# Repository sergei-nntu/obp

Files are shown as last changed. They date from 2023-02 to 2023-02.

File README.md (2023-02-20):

# Open Battery Pack (OBP-1)

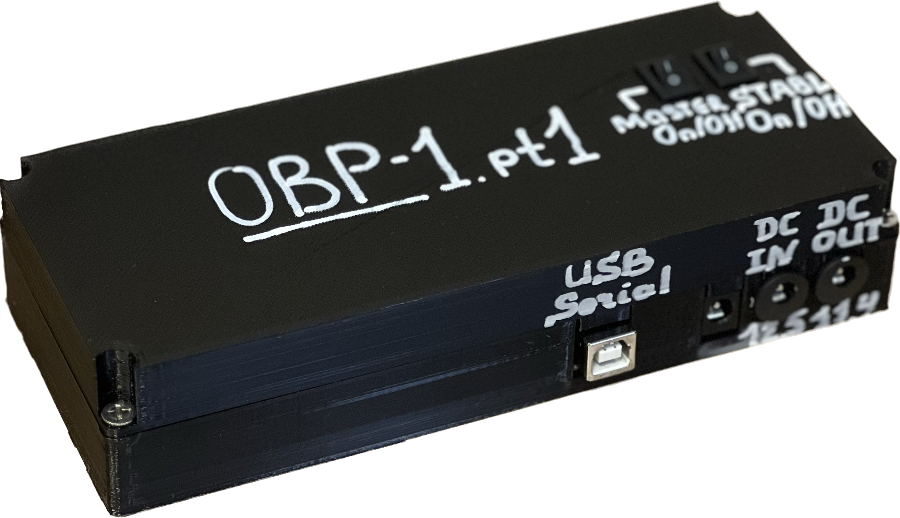
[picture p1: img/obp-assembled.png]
OBP Assembled


Arduino-based open-source hardware power bank for DIY and Robotic applications. This repository contains the schematics, Arduino firmware, python library for connection from the computer and FreeCAD case design files. 

# Installing Arduino code
Arduino source code is located in folder `src/arduino/OpenBatteryPack`. Open it with Arduino IDE and flash it into your Arduino board.

# Python library example
Flash the Arduino firmware into your board. Make sure it is connected through USB. Then run the example:

`cd src/python`

`python3 example.py`

# Technical Documentation
The architecture documentation can be found in `doc` folder.

# Case 3D Printing
STL files for 3d printing can be found in `case` folder. 
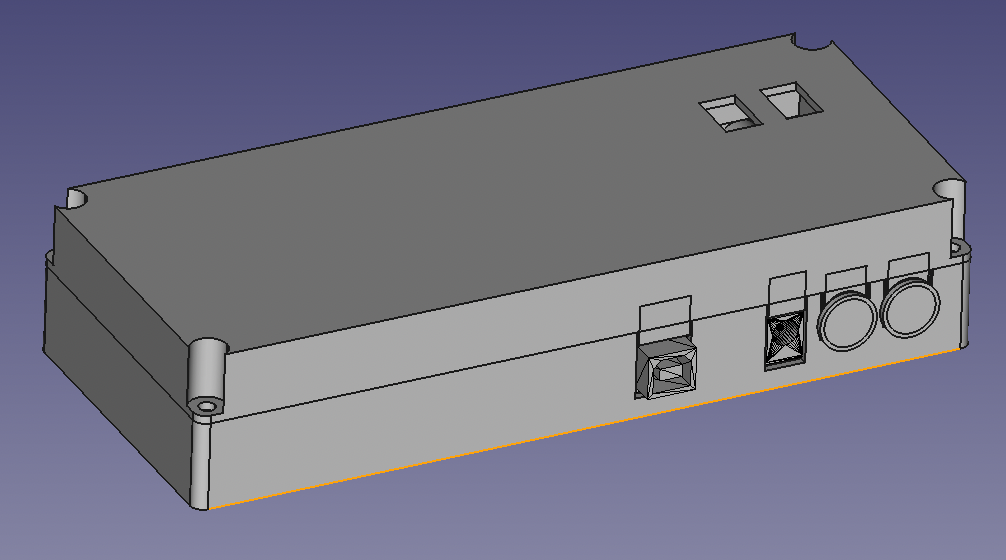
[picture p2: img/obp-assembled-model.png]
OBP Assembled Model


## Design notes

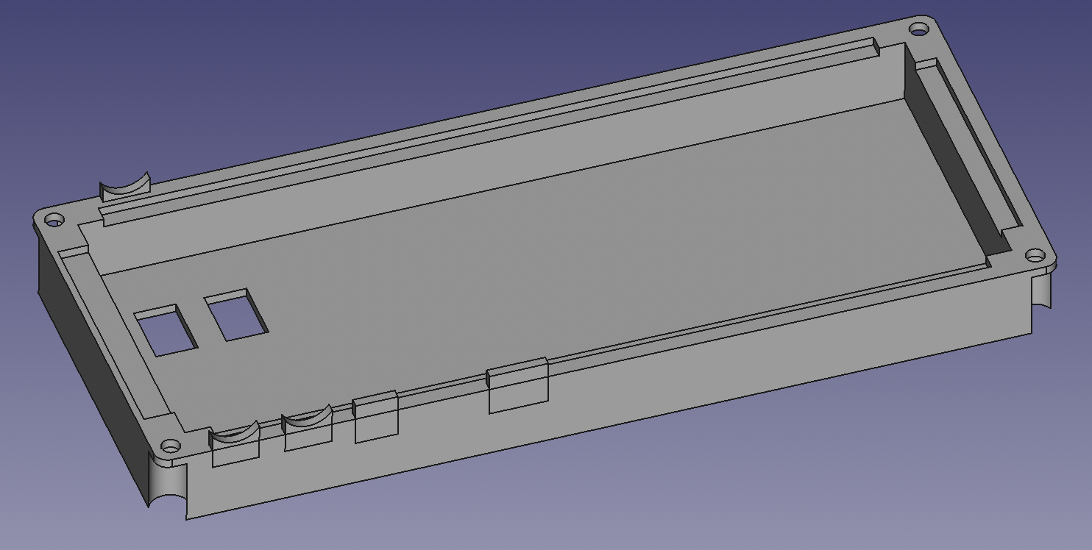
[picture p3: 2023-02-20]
img/obp-cover-model.png

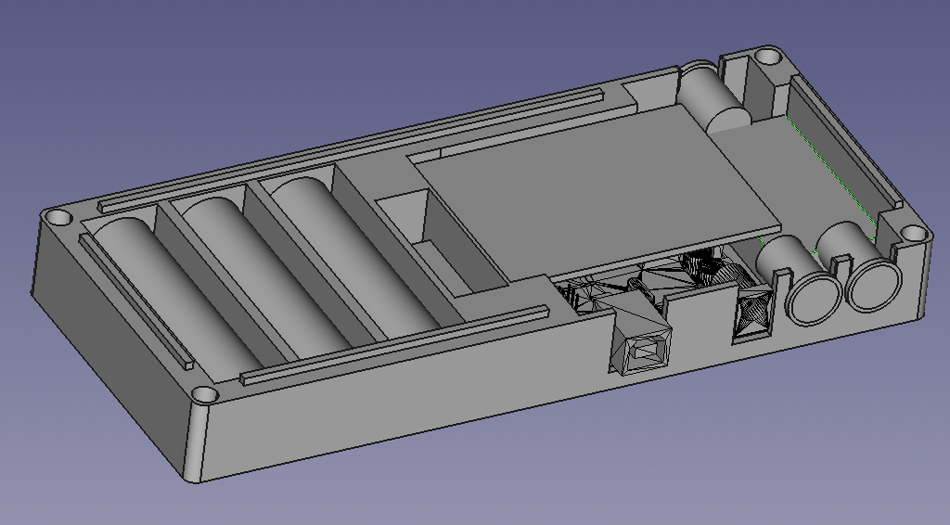
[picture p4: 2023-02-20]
img/obp-case-model.png

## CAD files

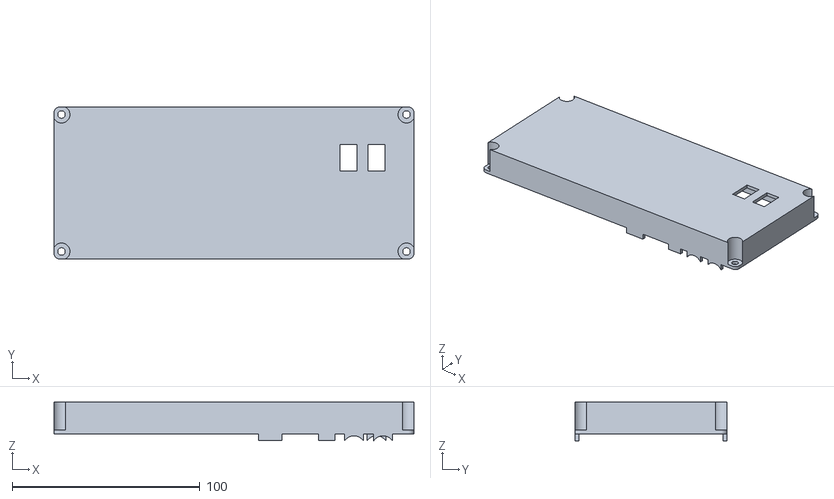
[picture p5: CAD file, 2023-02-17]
case/OBP_1_cover.stl
192.0 x 81.0 x 20.7

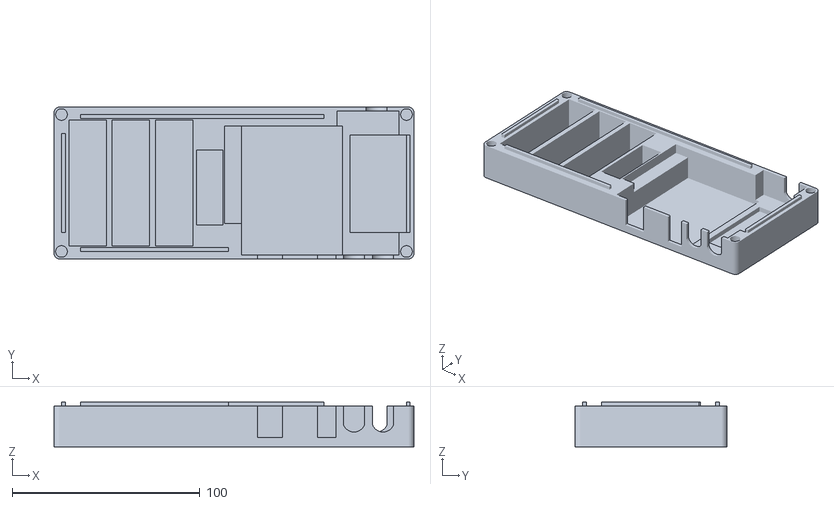
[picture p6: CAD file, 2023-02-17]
case/OBP_1_case.stl
192.0 x 81.0 x 24.0

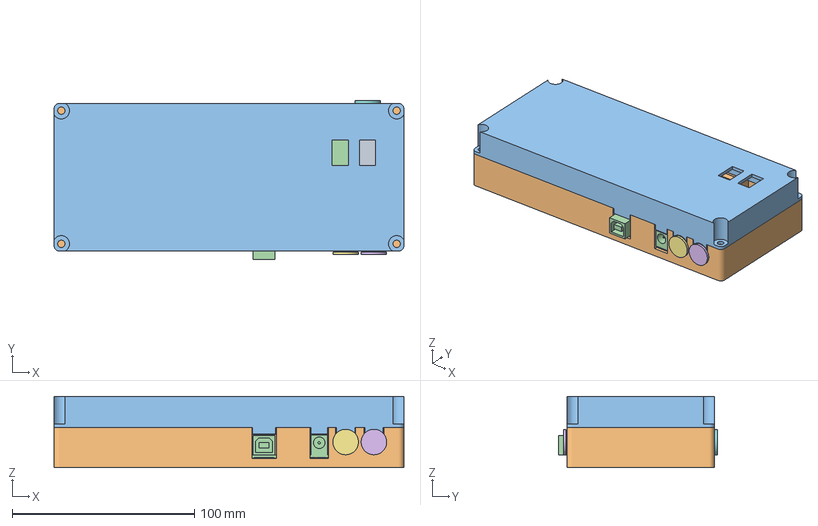
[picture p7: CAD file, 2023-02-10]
case/OpenBatteryPack_pt1.FCStd
192.0 x 87.0 x 39.0 mm
18650 Battery
18650 Battery001
18650 Battery002
Main Board
Current Sensor
DC Jack
DC Jack001
DC Jack002
DC-DC Step Up
Cover
Arduino.ipt

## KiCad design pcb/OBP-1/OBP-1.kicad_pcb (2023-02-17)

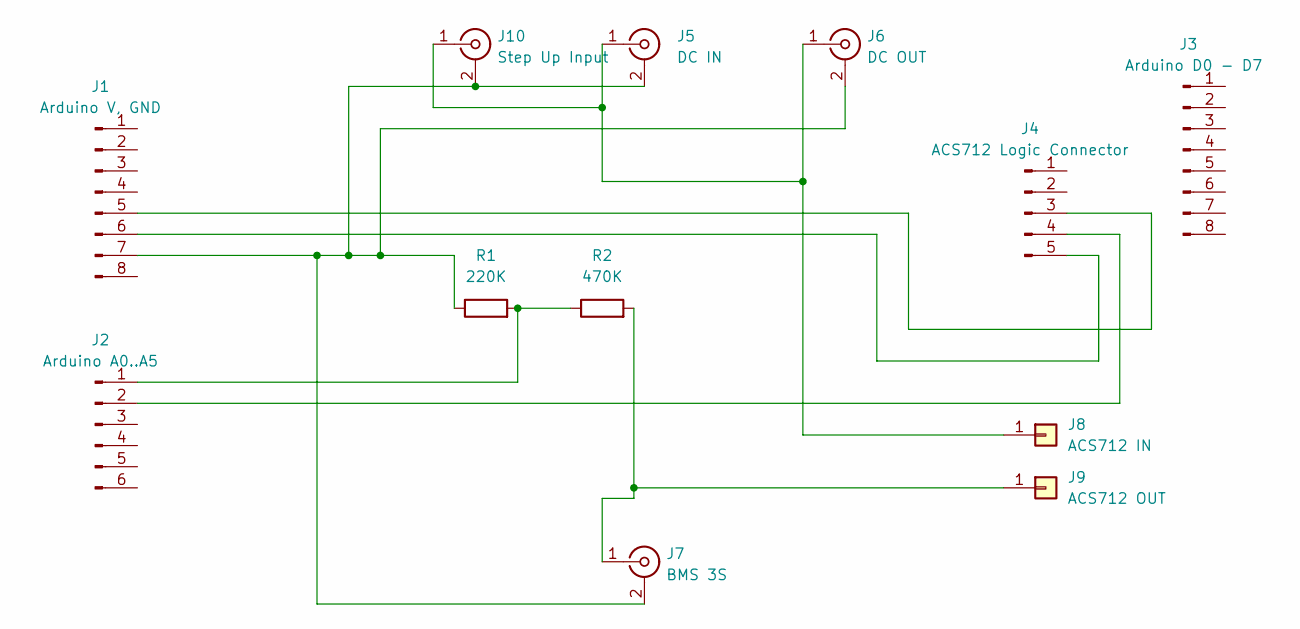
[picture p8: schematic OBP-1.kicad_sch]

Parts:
J1: Arduino V, GND; PinHeader_1x08_P2.54mm_Vertical
J2: Arduino A0..A5; PinHeader_1x06_P2.54mm_Vertical
J3: Arduino D0 - D7; PinHeader_1x08_P2.54mm_Vertical
J4: ACS712 Logic Connector; PinHeader_1x05_P2.54mm_Vertical
J5: DC IN; SolderWire-0.1sqmm_1x02_P3.6mm_D0.4mm_OD1mm
J6: DC OUT; SolderWire-0.1sqmm_1x02_P3.6mm_D0.4mm_OD1mm
J7: BMS 3S; SolderWire-0.1sqmm_1x02_P3.6mm_D0.4mm_OD1mm
J8: ACS712 IN; SolderWire-0.1sqmm_1x01_D0.4mm_OD1mm
J9: ACS712 OUT; SolderWire-0.1sqmm_1x01_D0.4mm_OD1mm
J10: Step Up Input; SolderWire-0.1sqmm_1x02_P3.6mm_D0.4mm_OD1mm
R1: 220K; R_Axial_DIN0207_L6.3mm_D2.5mm_P10.16mm_Horizontal
R2: 470K; R_Axial_DIN0207_L6.3mm_D2.5mm_P10.16mm_Horizontal

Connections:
unnamed: J1.5, J4.3
unnamed: J1.6, J4.5
unnamed: J1.7, J5.2 (Ext), J6.2 (Ext), J7.2 (Ext), J10.2 (Ext), R1.1
unnamed: J2.1, R1.2, R2.1
unnamed: J2.2, J4.4
unnamed: J5.1 (In), J6.1 (In), J8.1, J10.1 (In)
unnamed: J7.1 (In), J9.1, R2.2

Board: 2 copper layers, 12 parts (0 on the bottom side), 7 nets, no tracks yet.

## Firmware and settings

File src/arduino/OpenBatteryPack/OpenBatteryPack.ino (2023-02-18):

#include <EEPROM.h>

#include <LowPower.h>

// BATTERY CHARGE CONTROLLER FUNCTIONS

#define OBP_MAX_CAPACITY 10000 // mAh

int obp_voltage = 0;      // in mV
int obp_current_draw = 0; // in mA
int obp_soc = 2000;       // in mAh

// BATTERY PACK HARDWARE PARAMETERS

#define OBP_MAX_V       12600 // mV
#define OBP_MIN_V       9000  // mV

#define OBP_DIVISOR_R1  220
#define OBP_DIVISOR_R2  470

#define OBP_REF_V       5000
#define OBP_ADC_MAX     1024

#define OBP_V_PIN       A0
#define OBP_I_PIN       A1

#define OBP_STATUS_UNKNOWN        0x00
#define OBP_STATUS_IDLE           0x01
#define OBP_STATUS_DISCHARGING    0x02
#define OBP_STATUS_CHARGING       0x03
#define OBP_STATUS_FULLY_CHARGED  0x04

#define OBP_FSM_STATE_WAITING_FOR_ZERO  0x01
#define OBP_FSM_STATE_ZERO_CURRENT      0x02
#define OBP_FSM_STATE_NON_ZERO_CURRENT  0x03

#define OBP_AFTER_ZERO_ITERATIONS       10  // Number of 8 second intervals to check the voltage drop at non-zero current 

#define OBP_MAX_SENSED_CURRENT  20000   // mA
#define OBP_MIN_SENSED_CURRENT  -20000  // mA
#define OBP_NEAR_ZERO_CURRENT   250 // mA
#define OBP_SIGNIFICANT_CURRENT 1000 // mA
#define OBP_MAX_CURRENT_VOLTAGE 4500 // mV
#define OBP_MIN_CURRENT_VOLTAGE 500 // mV

#define OBP_EEPROM_POS_CURRENT_I_ADDR         0*sizeof(int)
#define OBP_EEPROM_POS_CURRENT_DELTA_U_ADDR   1*sizeof(int)
#define OBP_EEPROM_NEG_CURRENT_I_ADDR         2*sizeof(int)
#define OBP_EEPROM_NEG_CURRENT_DELTA_U_ADDR   3*sizeof(int)

// Corresponds to WAITING_FOR_ZERO state of FSM
unsigned char after_zero_iterations = OBP_AFTER_ZERO_ITERATIONS+1;
unsigned char obp_fsm_state = OBP_FSM_STATE_WAITING_FOR_ZERO;
int last_zero_current_voltage = 0;

unsigned char obp_status = OBP_STATUS_IDLE;

bool obp_flag_low_voltage = false;
bool obp_flag_high_voltage = false;
bool obp_flag_overheat = false;
bool obp_flag_short_circuit= false;

// OPEN SERIAL PERIPHERAL FUNCTIONS

#define OSP_MSG_DEV_INDEX     2
#define OSP_MSG_CMD_INDEX     3
#define OSP_BYTE_PARAM_INDEX      4
#define OSP_INT_PARAM_MSB_INDEX   5
#define OSP_INT_PARAM_LSB_INDEX   4 

#define OSP_DEV_GENERIC       0 
#define OSP_DEV_ORM           1 // Open Robotic Manipulator
#define OSP_DEV_OBP           2 // Open Battery Pack 
#define OSP_DEV_O2D           3 // Open Differential Drive

#define OSP_CMD_REQ_DEV_TYPE  1

#define OSP_OBP_CMD_REQ_SOC       0x01
#define OSP_OBP_CMD_REQ_VOLTAGE   0x02
#define OSP_OBP_CMD_REQ_CURRENT   0x03
#define OSP_OBP_CMD_REQ_STATUS    0x04

#define OSP_INFO_DEV_TYPE         0x11
#define OSP_OBP_INFO_SOC          0x11
#define OSP_OBP_INFO_VOLTAGE      0x12
#define OSP_OBP_INFO_CURRENT      0x13
#define OSP_OBP_INFO_STATUS       0x14

#define OSP_DEV_CURRENT           OSP_DEV_OBP

#define OSP_COMMAND_LENGTH        10
#define OSP_BUFFER_SIZE           10

char            osp_output_buffer[OSP_BUFFER_SIZE];
unsigned char   osp_input_buffer[OSP_BUFFER_SIZE];
int             osp_ptr=0;

const char osp_command_template[] = {0xFF, 0xAA, 0x00, 0x00, 0x00, 0x00, 0x00, 0x00, 0x55, 0x77};

// HANDING OSP GENERIC COMMANDS

void osb_info_dev_type(){
  osp_prepare_output_buffer();
  osp_output_buffer[OSP_MSG_DEV_INDEX] = OSP_DEV_GENERIC;
  osp_output_buffer[OSP_MSG_CMD_INDEX] = OSP_INFO_DEV_TYPE;
  osp_output_buffer[OSP_BYTE_PARAM_INDEX] = OSP_DEV_CURRENT; // Returning the current device type as a parameter
  Serial.write(osp_output_buffer, OSP_COMMAND_LENGTH);
}

void osp_handle_generic_command(){
  int cmd = osp_input_buffer[OSP_MSG_CMD_INDEX];  
  if (cmd == OSP_CMD_REQ_DEV_TYPE) {
    // HERE WE MUST RESPONSE WITH A DEV TYPE
    osb_info_dev_type();
  }
}

void osp_prepare_output_buffer(){
  for(int i=0;i<OSP_BUFFER_SIZE;i++) {
    osp_output_buffer[i] = osp_command_template[i];
  }
}

// HANDLING OBP COMMANDS
void osp_opb_send_info_soc(){
  osp_prepare_output_buffer();
    
  unsigned int soc_int = obp_soc;
  osp_output_buffer[OSP_MSG_DEV_INDEX] = OSP_DEV_OBP;
  osp_output_buffer[OSP_MSG_CMD_INDEX] = OSP_OBP_INFO_SOC;
  osp_output_buffer[OSP_INT_PARAM_LSB_INDEX] = soc_int & 0xFF;
  osp_output_buffer[OSP_INT_PARAM_MSB_INDEX] = soc_int >> 8;
  
  Serial.write(osp_output_buffer, OSP_COMMAND_LENGTH);
}

void osp_opb_send_info_voltage(){
  osp_prepare_output_buffer();
  unsigned int voltage_int = obp_voltage ; // Voltage in mV

  osp_output_buffer[OSP_MSG_DEV_INDEX] = OSP_DEV_OBP;
  osp_output_buffer[OSP_MSG_CMD_INDEX] = OSP_OBP_INFO_VOLTAGE;
  osp_output_buffer[OSP_INT_PARAM_LSB_INDEX] = voltage_int & 0xFF;
  osp_output_buffer[OSP_INT_PARAM_MSB_INDEX] = voltage_int >> 8;
  
  Serial.write(osp_output_buffer, OSP_COMMAND_LENGTH);  
}

void osp_opb_send_info_current(){
  osp_prepare_output_buffer();
  int  current_int = obp_current_draw; // mA 
  osp_output_buffer[OSP_MSG_DEV_INDEX] = OSP_DEV_OBP;
  osp_output_buffer[OSP_MSG_CMD_INDEX] = OSP_OBP_INFO_CURRENT;

  osp_output_buffer[OSP_INT_PARAM_LSB_INDEX] = current_int & 0xFF;
  osp_output_buffer[OSP_INT_PARAM_MSB_INDEX] = current_int >> 8;
   
  Serial.write(osp_output_buffer, OSP_COMMAND_LENGTH);   
}

void osp_opb_send_info_status(){
  
}

void osp_handle_obp_command(){
  int cmd = osp_input_buffer[OSP_MSG_CMD_INDEX];  
  if (cmd == OSP_OBP_CMD_REQ_SOC) {
    // RESPONSE WITH A CURRENT SOC STATE
    osp_opb_send_info_soc();
  }
  if (cmd == OSP_OBP_CMD_REQ_VOLTAGE) {
    // RESPONSE WITH A CURRENT VOLTAGE LEVEL
    osp_opb_send_info_voltage();
  }
  if (cmd == OSP_OBP_CMD_REQ_CURRENT) {
    // RESPONSE WITH A CURRENT CURRENT DRAW
    osp_opb_send_info_current();
  }
  if (cmd == OSP_OBP_CMD_REQ_STATUS) {
    // RESPONSE WITH A CURRENT BATTERY STATUS
    osp_opb_send_info_status();
  }
}

void osp_handle_command(){
  int dev = osp_input_buffer[OSP_MSG_DEV_INDEX];
  
  if (dev == OSP_DEV_GENERIC) {
    osp_handle_generic_command();
  } else if (dev == OSP_DEV_CURRENT) {
    if (dev == OSP_DEV_OBP) {
      osp_handle_obp_command();
    }
  } else {
    // ERROR CONDITION. THE CLIENT MUST NOT SEND THE COMMAND WHICH ARE NOT FOR EITHER GENERIC OR CURRENT DEV TYPE
    // DOING NOTHING FOR NOW
  }
}

void setup_osp(){
  Serial.begin(115200);
  Serial.setTimeout(0.01);  
}

void loop_osp(){
  if(Serial.available()){
    char b = Serial.read();
    if(osp_command_template[osp_ptr]==b || osp_command_template[osp_ptr]==0){
      osp_input_buffer[osp_ptr] = b;
      osp_ptr++; 
      if(osp_ptr==OSP_COMMAND_LENGTH){
        osp_handle_command();
        osp_ptr = 0;
      }
    } else {
      osp_ptr = 0;
    }
  }
}

// OPB Logic
int pos_i =0;
int pos_delta_u = 0;
int neg_i=0;
int neg_delta_u = 0;

bool obp_i_delta_u_EEPROM_stored = false; 

void obp_store_i_deltaU_EEPROM(){
  if(pos_i>0 && neg_i<0){
    if (obp_i_delta_u_EEPROM_stored==false) {
      // Write the values to EEPROM
      // 1. Get the values currently written to EEPROM
      int loaded_pos_i = 0;
      int loaded_pos_delta_U = 0;
      int loaded_neg_i = 0;
      int loaded_neg_delta_U = 0; 

      EEPROM.get(OBP_EEPROM_POS_CURRENT_I_ADDR, loaded_pos_i);
      EEPROM.get(OBP_EEPROM_POS_CURRENT_DELTA_U_ADDR, loaded_pos_delta_U);

      EEPROM.get(OBP_EEPROM_NEG_CURRENT_I_ADDR, loaded_neg_i);
      EEPROM.get(OBP_EEPROM_NEG_CURRENT_DELTA_U_ADDR, loaded_neg_delta_U);

      // 2. Compare the values from EEPROM with the current values, and write the changes 
      if(loaded_pos_i != pos_i){
        EEPROM.put(OBP_EEPROM_POS_CURRENT_I_ADDR, pos_i);
      }
      if(loaded_pos_delta_U != pos_delta_u) {
        EEPROM.put(OBP_EEPROM_POS_CURRENT_DELTA_U_ADDR, pos_delta_u);
      }

      if(loaded_neg_i != neg_i) {
        EEPROM.put(OBP_EEPROM_NEG_CURRENT_I_ADDR, neg_i);        
      }   

      if(loaded_neg_delta_U != neg_delta_u) {
        EEPROM.put(OBP_EEPROM_NEG_CURRENT_DELTA_U_ADDR, neg_delta_u);  
      }   

      obp_i_delta_u_EEPROM_stored=true;
    }
  }
}

void obp_load_i_deltaU_EEPROM(){
  int loaded_pos_i = 0;
  int loaded_pos_delta_U = 0;
  int loaded_neg_i = 0;
  int loaded_neg_delta_U = 0;  

  EEPROM.get(OBP_EEPROM_POS_CURRENT_I_ADDR, loaded_pos_i);
  EEPROM.get(OBP_EEPROM_POS_CURRENT_DELTA_U_ADDR, loaded_pos_delta_U);

  EEPROM.get(OBP_EEPROM_NEG_CURRENT_I_ADDR, loaded_neg_i);
  EEPROM.get(OBP_EEPROM_NEG_CURRENT_DELTA_U_ADDR, loaded_neg_delta_U);


  if(loaded_pos_i>0 && loaded_neg_i<0){
    // Load only if the values are respectively below and above zero
    pos_i = loaded_pos_i;
    pos_delta_u = loaded_pos_delta_U;
    neg_i = loaded_neg_i;
    neg_delta_u = loaded_neg_delta_U;
  }
}

void obp_save_i_delta_u(int i, int delta_u){
  if(i>=0){
    pos_i = i;
    pos_delta_u = delta_u;
  } else {
    neg_i = i;
    neg_delta_u = delta_u;
  }  
}

long int obp_get_delta_u(long int i){
    if(i>=0){
      if (pos_i ==0){
        return 0;
      }      
      return i * pos_delta_u / pos_i;
    } else {
      if(neg_i ==0) {
        return 0;
      }      
      return i * neg_delta_u / neg_i;
    }
    return 0;
}

void obp_control_thread(){
  // OPTION 1. MVP
  // Just read the current V and I values
  //  - they may also be converted to the battery chanrge level using some basic conversion table/formula
  long int voltage_adc = analogRead(OBP_V_PIN);
  obp_voltage = (OBP_REF_V * voltage_adc / OBP_ADC_MAX) * (OBP_DIVISOR_R1+OBP_DIVISOR_R2) / (OBP_DIVISOR_R1); 

  long int current_adc = analogRead(OBP_I_PIN);
  long int current_adc_v = current_adc * OBP_REF_V / OBP_ADC_MAX;
  
  obp_current_draw = OBP_MIN_SENSED_CURRENT + (current_adc_v - OBP_MIN_CURRENT_VOLTAGE) * ((long)OBP_MAX_SENSED_CURRENT-OBP_MIN_SENSED_CURRENT) / (OBP_MAX_CURRENT_VOLTAGE - OBP_MIN_CURRENT_VOLTAGE);
  //obp_current_draw = -current_adc_v;
  // RECORD THE DELTA U FOR THE CERTAIN VALUE OF I

  if (obp_current_draw>=-OBP_NEAR_ZERO_CURRENT && obp_current_draw<=OBP_NEAR_ZERO_CURRENT){
    // Record U and nullify N
    after_zero_iterations = 0;
    last_zero_current_voltage = obp_voltage;
    obp_fsm_state = OBP_FSM_STATE_ZERO_CURRENT;
  } else {
    if(obp_fsm_state == OBP_FSM_STATE_ZERO_CURRENT || obp_fsm_state == OBP_FSM_STATE_NON_ZERO_CURRENT) {
      obp_fsm_state = OBP_FSM_STATE_NON_ZERO_CURRENT;
      after_zero_iterations++;
      if(after_zero_iterations > OBP_AFTER_ZERO_ITERATIONS){
        obp_fsm_state = OBP_FSM_STATE_WAITING_FOR_ZERO;
        obp_store_i_deltaU_EEPROM(); // Once the period of measuring of the deltas is ended - store the results to EEPROM
      }
    }
    if(obp_fsm_state == OBP_FSM_STATE_NON_ZERO_CURRENT) {
      int deltaU = obp_voltage - last_zero_current_voltage;
      obp_save_i_delta_u(obp_current_draw, deltaU);
    }
  }

  // ESTIMATE THE SOC
  long int deltaUExpected = obp_get_delta_u(obp_current_draw);
  long int noLoadU = obp_voltage - deltaUExpected;

  obp_soc = OBP_MAX_CAPACITY * (noLoadU - OBP_MIN_V) / (OBP_MAX_V - OBP_MIN_V);
  if (obp_soc<0){
    obp_soc = 0;
  }
  if(obp_soc > OBP_MAX_CAPACITY){
    obp_soc = OBP_MAX_CAPACITY;    
  }
}

void setup() {
  // put your setup code here, to run once:
  setup_osp();
  obp_load_i_deltaU_EEPROM();
}

void loop() {
  // put your main code here, to run repeatedly:
  loop_osp();
  obp_control_thread();
  osp_opb_send_info_soc();  
  osp_opb_send_info_current();
  osp_opb_send_info_voltage();
  osb_info_dev_type();
  delay(100);
  
  LowPower.powerDown(SLEEP_1S, ADC_OFF, BOD_OFF);  
}

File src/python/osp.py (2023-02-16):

# Importing Libraries
import serial
import time
import math
import threading
import glob
import sys

# OSP DATA INDICIES WITHIN THE MESSAGE

OSP_MSG_DEV_INDEX = 2
OSP_MSG_CMD_INDEX = 3
OSP_BYTE_PARAM_INDEX = 4
OSP_INT_PARAM_MSB_INDEX = 5
OSP_INT_PARAM_LSB_INDEX = 4 

# OSP DEVICE TYPES

OSP_DEV_GENERIC = 0
OSP_DEV_ORM = 1
OSP_DEV_OBP = 2
OSP_DEV_O2D = 3

# OSP COMMANDS 

OSP_CMD_REQ_DEV_TYPE = 0x01
OSP_INFO_DEV_TYPE = 0x11
OSP_OBP_CMD_REQ_SOC = 0x01
OSP_OBP_CMD_REQ_VOLTAGE = 0x02
OSP_OBP_CMD_REQ_CURRENT = 0x03
OSP_OBP_CMD_REQ_STATUS = 0x04

OSP_OBP_INFO_SOC = 0x11
OSP_OBP_INFO_VOLTAGE = 0x12
OSP_OBP_INFO_CURRENT = 0x13
OSP_OBP_INFO_STATUS = 0x14

OSP_DEV_CURRENT = OSP_DEV_OBP

OSP_COMMAND_LENGTH = 10
OSP_BUFFER_SIZE = 10


class OSP:
    command_buffer_pattern = [ 0xFF, 0xAA, 0x00, 0x00, 0x00, 0x00, 0x00, 0x00, 0x55, 0x77]
    input_index = 0
    output_buffer = []
    input_buffer = [0, 0, 0, 0, 0, 0, 0, 0, 0, 0]
    osp_serial = None
    osp_dev_type = 0
    output_thread = None
    input_thread = None
    closed = False 
    
    soc = 0
    voltage = 0
    current = 0
    
    
    def __init__(self,port_name):
        # '/dev/ttyACM1'
        self.osp_serial = serial.Serial(port=port_name, baudrate=115200, timeout=.1)
        #print("Starting Output Thread")
        self.output_thread = threading.Thread(target=self.output_thread, daemon=True)  
        self.output_thread.start()
        #print("Starting Input Thread")
        self.input_thread = threading.Thread(target=self.input_thread, daemon=True)  
        self.input_thread.start()
    
    def stop(self):
        self.closed = True
        self.osp_serial.close()
        
    
    def get_dev_type(self):
        return self.osp_dev_type
    
    def output_thread(self):
        while self.closed is not True:
            if len(self.output_buffer) > 0:
                #print("Sending Byte"+str(self.output_buffer[0]));
                self.osp_serial.write(bytes([self.output_buffer.pop(0)]))
                time.sleep(0.001)
     
    def osp_send_command(self,cmd_bytes):
        self.output_buffer += cmd_bytes
        
    def osp_req_device_type(self):
        cmd_bytes = self.command_buffer_pattern.copy()
        cmd_bytes[OSP_MSG_DEV_INDEX] = OSP_DEV_GENERIC
        cmd_bytes[OSP_MSG_CMD_INDEX] = OSP_CMD_REQ_DEV_TYPE
        self.osp_send_command(cmd_bytes)
                  
    def osp_info_dev_type(self):
        self.osp_dev_type = self.input_buffer[OSP_BYTE_PARAM_INDEX]
        #print("Device Type Received:",self.osp_dev_type);
                
    def osp_obp_info_soc(self):
        soc_lsb = self.input_buffer[OSP_INT_PARAM_LSB_INDEX]
        soc_msb = self.input_buffer[OSP_INT_PARAM_MSB_INDEX]
        soc = soc_lsb | (soc_msb << 8)
        self.soc = soc
        #print("SOC: "+str(soc))
        
    def osp_obp_info_current(self):
        current_lsb = self.input_buffer[OSP_INT_PARAM_LSB_INDEX]
        current_msb = self.input_buffer[OSP_INT_PARAM_MSB_INDEX]
        current = current_lsb | (current_msb << 8)
        if current >> 15 != 0:
            # Two's complement decoding
            current = -((~current & 0xffff)+1)
        self.current = current
        #print("I: "+str(current)+" mA")
        
    def osp_obp_info_voltage(self):
        v_lsb = self.input_buffer[OSP_INT_PARAM_LSB_INDEX]
        v_msb = self.input_buffer[OSP_INT_PARAM_MSB_INDEX]
        v = v_lsb | (v_msb << 8)
        self.voltage = v
        #print("V: "+str(v)+" mV")

    def info_current_angle(self):
        actuator_no = self.input_buffer[3]
        angle = self.input_buffer[4] | (self.input_buffer[5] << 8)
#        if actuator_no == 5:
#            print("Current Angle For Actuator "+str(actuator_no)+" is "+str(angle))
   
    def info_current_speed(self):
        actuator_no = self.input_buffer[3]
        speed = self.input_buffer[4] | (self.input_buffer[5] << 8)
        #print("Current Speed For Actuator "+str(actuator_no)+" is "+str(speed))
    
    def input_thread(self):
        while self.closed is not True:
            try:
                bts = self.osp_serial.read()
                #print("Bytes_Read:"+str(bts))
                if len(bts)>0:
                    #print("Bytes_Read:"+str(bts))
                    bt = bts[0]
                    if self.command_buffer_pattern[self.input_index] == bt or self.command_buffer_pattern[self.input_index] ==0:
                        self.input_buffer[self.input_index] = bt
                        self.input_index += 1
                        if self.input_index >= len(self.command_buffer_pattern):
                            #print("Command Received:"+str(self.input_buffer))
                            if self.input_buffer[OSP_MSG_DEV_INDEX] == OSP_DEV_OBP:
                                if self.input_buffer[OSP_MSG_CMD_INDEX] ==  OSP_OBP_INFO_SOC:
                                    self.osp_obp_info_soc()
                                if self.input_buffer[OSP_MSG_CMD_INDEX] ==  OSP_OBP_INFO_CURRENT:
                                    self.osp_obp_info_current()
                                if self.input_buffer[OSP_MSG_CMD_INDEX] ==  OSP_OBP_INFO_VOLTAGE:
                                    self.osp_obp_info_voltage()
                            if self.input_buffer[OSP_MSG_DEV_INDEX] == OSP_DEV_GENERIC:
                                if self.input_buffer[OSP_MSG_CMD_INDEX] == OSP_INFO_DEV_TYPE:
                                    self.osp_info_dev_type()
                            self.input_index = 0
                    else:
                        self.input_index = 0
                time.sleep(0.000001)
            except serial.serialutil.SerialException:
                break # Exiting while loop
        


def find_osp_peripheral(osp_dev_type):
    if sys.platform.startswith('win'):
        ports = ['COM%s' % (i + 1) for i in range(256)]
    elif sys.platform.startswith('linux') or sys.platform.startswith('cygwin'):
        # this excludes your current terminal "/dev/tty"
        ports = glob.glob('/dev/tty.usb*')
    elif sys.platform.startswith('darwin'):
        ports = glob.glob('/dev/tty.usb*')
    else:
        raise EnvironmentError('Unsupported platform')
    
    devs = list(map(lambda port: OSP(port), ports))
    
    time.sleep(3) # Timeout to receive the first messages from the devices
    
    devs_of_type = filter(lambda d: d.get_dev_type() == osp_dev_type, devs)
    
    devs_of_wrong_type = filter(lambda d: d.get_dev_type() != osp_dev_type, devs)
    for dev in devs_of_wrong_type:
        dev.stop()
    
    return list(devs_of_type)

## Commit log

2023-02-10 Initial Version. Added README and LICENSE files. Added FreeCad model for the OBP-1 case
    [OpenBatteryPack_pt1.FCStd]
2023-02-16 Open Battery Pack Arduino Firmware Added
2023-02-17 OBP-1. First version of schematics and PCB for main board added
    [OBP-1.kicad_pcb, OBP-1.kicad_sch]
2023-02-17 Added STL files for OBP-1 Case and Cover
    [OBP_1_case.stl, OBP_1_cover.stl]
2023-02-18 Error in FSM states definition fixed. Architecture doc added
    [OpenBatteryPack.ino]
